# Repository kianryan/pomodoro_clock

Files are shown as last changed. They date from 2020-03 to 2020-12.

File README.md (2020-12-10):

## Introduction

Pomodoro Clock for AtTiny84 and MAX7219.

## Prerequisites

Arduino Cli

```
choco install arduino-cli
```

Install ATTinyCore Core

```
arduino-cli core install ATTinyCore:avr
```

## Building

* Arduino CLI
* USBAsp

Compiles, generates build asset in /build and uploads via ASP.

```
arduino-cli compile --fqbn ATTinyCore:avr:attinyx4; arduino-cli upload --fqbn ATTinyCore:avr:attinyx4 -P usbasp
```

## Board and Schematics

Eagle designs are available in /eagle

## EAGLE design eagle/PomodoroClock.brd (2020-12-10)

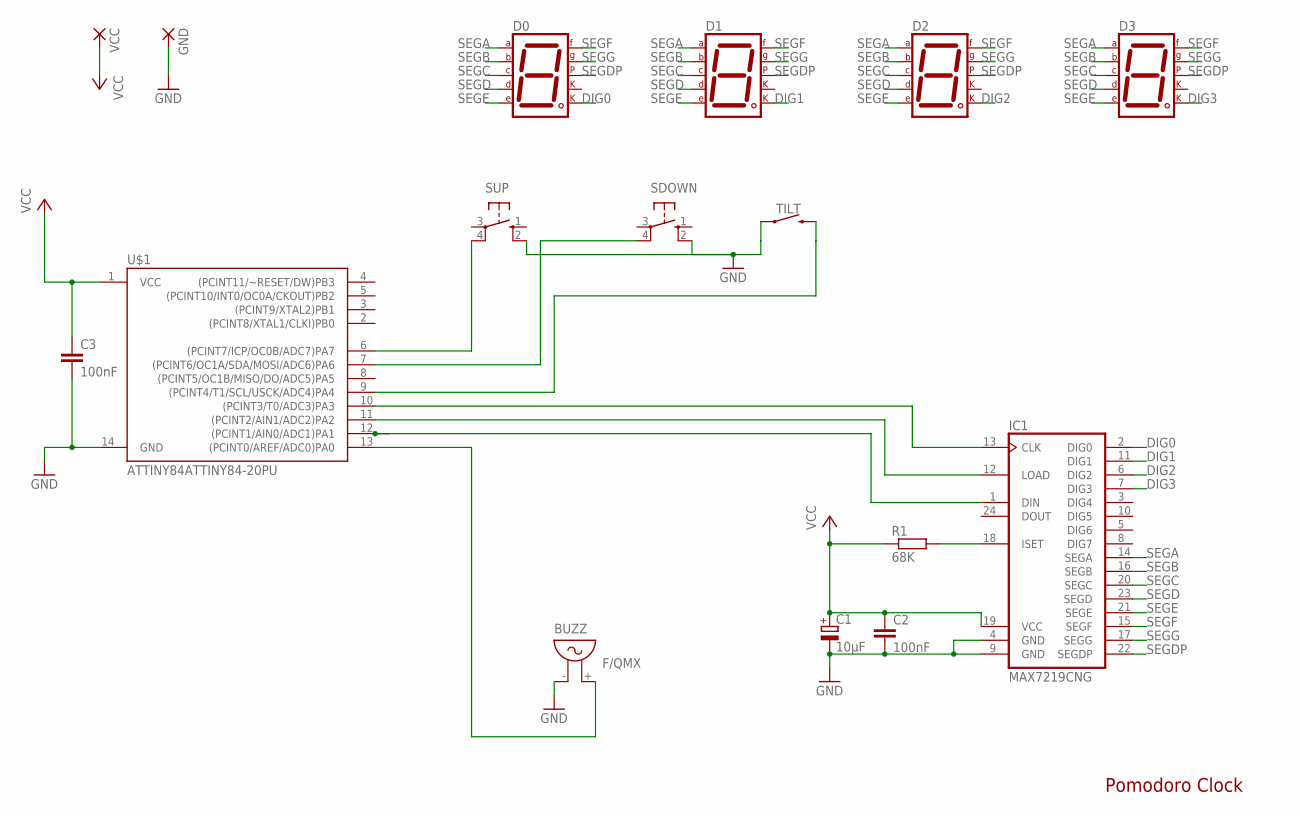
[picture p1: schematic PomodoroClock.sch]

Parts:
BUZZ: F/QMX
C1: 10μF; E2,5-6E
C2, C3: 100nF; C025-025X050
D0, D1, D2, D3: 7SEG-CK; 7SEG-13
GND: 3,81/1,4
IC1: MAX7219CNG; DIL24-3
R1: 68K; 0207/10
SDOWN: 10-XX; B3F-10XX
SUP: 10-XX; B3F-10XX
TILT: TILT
U$1: ATTINY84ATTINY84-20PU; DIP14
VCC: 3,81/1,4

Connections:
DIG0: D0.8 (CK2), IC1.2 (DIG0)
DIG1: D1.8 (CK2), IC1.11 (DIG1)
DIG2: D2.8 (CK2), IC1.6 (DIG2)
DIG3: D3.8 (CK2), IC1.7 (DIG3)
GND: BUZZ.- (1), C1.-, C2.2, C3.2, GND.1, IC1.4 (GND), IC1.9 (GND), SDOWN.2 (S1), SUP.2 (S1), TILT.1 (3), U$1.14 (GND)
unnamed: IC1.13 (CLK), U$1.10 ((PCINT3/T0/ADC3)PA3)
unnamed: IC1.12 (LOAD), U$1.11 ((PCINT2/AIN1/ADC2)PA2)
unnamed: IC1.1 (DIN), U$1.12 ((PCINT1/AIN0/ADC1)PA1)
unnamed: BUZZ.+ (2), U$1.13 ((PCINT0/AREF/ADC0)PA0)
unnamed: SUP.4 (P1), U$1.6 ((PCINT7/ICP/OC0B/ADC7)PA7)
unnamed: SDOWN.4 (P1), U$1.7 ((PCINT6/OC1A/SDA/MOSI/ADC6)PA6)
unnamed: IC1.18 (ISET), R1.2
SEGA: D0.7 (A), D1.7 (A), D2.7 (A), D3.7 (A), IC1.14 (SEGA)
SEGB: D0.6 (B), D1.6 (B), D2.6 (B), D3.6 (B), IC1.16 (SEGB)
SEGC: D0.4 (C), D1.4 (C), D2.4 (C), D3.4 (C), IC1.20 (SEGC)
SEGD: D0.2 (D), D1.2 (D), D2.2 (D), D3.2 (D), IC1.23 (SEGD)
SEGDP: D0.5 (DP), D1.5 (DP), D2.5 (DP), D3.5 (DP), IC1.22 (SEGDP)
SEGE: D0.1 (E), D1.1 (E), D2.1 (E), D3.1 (E), IC1.21 (SEGE)
SEGF: D0.9 (F), D1.9 (F), D2.9 (F), D3.9 (F), IC1.15 (SEGF)
SEGG: D0.10 (G), D1.10 (G), D2.10 (G), D3.10 (G), IC1.17 (SEGG)
TILT: TILT.2 (4), U$1.9 ((PCINT4/T1/SCL/USCK/ADC4)PA4)
VCC: C1.+, C2.1, C3.1, IC1.19 (VCC), R1.1, U$1.1 (VCC), VCC.1

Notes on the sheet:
Pomodoro Clock

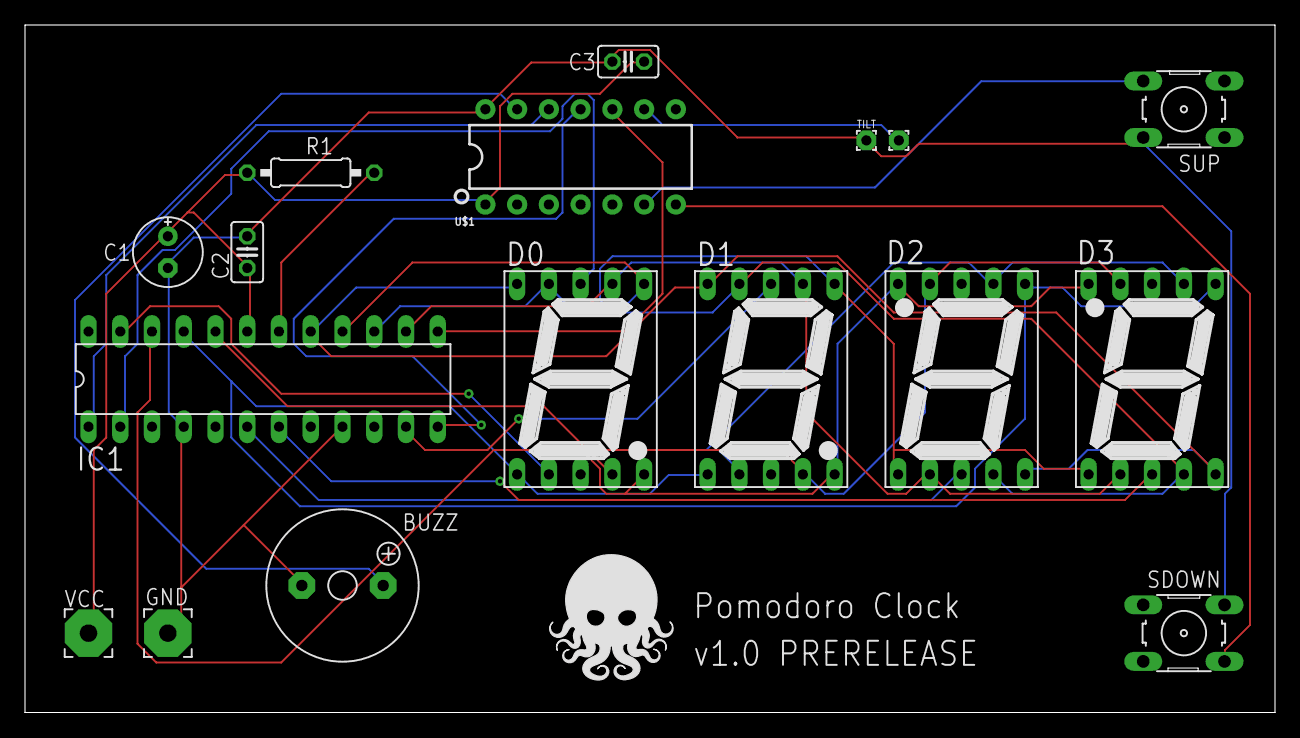
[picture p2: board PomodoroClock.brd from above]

Board: 2 copper layers, 100.0 x 55.0 mm, 16 parts (0 on the bottom side), 22 nets.

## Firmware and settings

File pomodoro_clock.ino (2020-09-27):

#include "LedControl.h"
#include "MilliClock.h"
#include "PomoTimer.h"
#include "TiltSwitch.h"
#include "EasingButton.h"
#include "ButtonManager.h"
#include "UiManager.h"
#include "Preflight.h"
#include <EEPROM.h>

MilliClock rtc;

int timers[] = {0, 0};

PomoTimer timer(&rtc);
TiltSwitch tiltSwitch(4);
ButtonManager buttonManager(&rtc, 6, 7, 5);
UiManager uiManager(&rtc, 1, 3, 2, 0);
Preflight preflight(&rtc, &timer);

bool direction;

bool alarmSilenced;


void setup() {

   // Serial for debugging
//    Serial.begin(9600);

   uiManager.startup();
   delay(1000);

   /* Initialize EEPROM, or timers from EEPROM */
   byte init = EEPROM.read(0);
//    if (init == 255) {
       timers[0] = 1200;
       timers[1] = 300;
    //    EEPROM.put(1, timers[0]);
    //    EEPROM.put(sizeof(int) + 1, timers[1]);
    //    EEPROM.put(0, 0);
//    } else {
//        EEPROM.get(1, timers[0]);
//        EEPROM.get(sizeof(int) + 1, timers[1]);
//    }

   direction = tiltSwitch.getState(); // Get an inital direction.
   preflight.start(timers[direction]);
}

void loop() {

    tiltSwitch.update();
    buttonManager.update();

    // On a change in tilt state,
    bool newDirection = tiltSwitch.getState();
    if (direction != newDirection) {
        direction = newDirection;

        preflight.start(timers[direction]);
    }

    if (preflight.isRunning()) {

        /* Take button input, if button press, increase duration
           of preflight, and increase time displayed on clock. */

        // check the button state.
        bool pause = false;
        switch (buttonManager.getState()) {
           case CHANGE_TIMER:
                int change = buttonManager.getChange(direction);

                timers[direction] = timer.changeTime(change);
                pause = true;
                break;
        }

       TimeSpan interval = preflight.time(pause); // get preflight time.
       if (interval.milliseconds() == 0) {        // update EEPROM with last set time.
           EEPROM.put((direction * sizeof(int)) + 1, timers[direction]);
           uiManager.resetAlarm();
       }

        if (preflight.isDisplayOn()) {
            uiManager.display(timer.time().totalseconds(), direction);
        } else {
            uiManager.clearDisplay();
        }
    } else {

        // check the button state.
        int buttonState = buttonManager.getState();
        switch (buttonState) {
            case NO_BUTTON:
                // Nothing to do here.
                break;
            case TOGGLE_TIMER:
                timer.startStop();
                break;
            case CHANGE_TIMER:
                timer.changeTime(buttonManager.getChange(direction));
                break;
        }

        // Get the time from the timer and display.
        TimeSpan interval = timer.time();
        unsigned long millis = interval.milliseconds();

        // If the timer is not currently running,
        // and there's time on the clock, start the timer.
        if (millis > 0 && ! timer.isRunning()) {
            uiManager.resetAlarm();
            timer.start();
        }
        // If there's no time on the clock, alarm.
        // If the button is depressed, silence.
        else if (millis == 0) {
            if (buttonState != NO_BUTTON) {
                uiManager.silenceAlarm();
            }
            uiManager.alarm();
        }

        uiManager.display(interval.totalseconds(), direction);
   }
}

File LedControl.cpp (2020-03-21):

/*
 *    LedControl.cpp - A library for controling Leds with a MAX7219/MAX7221
 *    Copyright (c) 2007 Eberhard Fahle
 *
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
 *    This permission notice shall be included in all copies or
 *    substantial portions of the Software.
 *
 *    THE SOFTWARE IS PROVIDED "AS IS", WITHOUT WARRANTY OF ANY KIND,
 *    EXPRESS OR IMPLIED, INCLUDING BUT NOT LIMITED TO THE WARRANTIES
 *    OF MERCHANTABILITY, FITNESS FOR A PARTICULAR PURPOSE AND
 *    NONINFRINGEMENT. IN NO EVENT SHALL THE AUTHORS OR COPYRIGHT
 *    HOLDERS BE LIABLE FOR ANY CLAIM, DAMAGES OR OTHER LIABILITY,
 *    WHETHER IN AN ACTION OF CONTRACT, TORT OR OTHERWISE, ARISING
 *    FROM, OUT OF OR IN CONNECTION WITH THE SOFTWARE OR THE USE OR
 *    OTHER DEALINGS IN THE SOFTWARE.
 */


#include "LedControl.h"

//the opcodes for the MAX7221 and MAX7219
#define OP_NOOP   0
#define OP_DIGIT0 1
#define OP_DIGIT1 2
#define OP_DIGIT2 3
#define OP_DIGIT3 4
#define OP_DIGIT4 5
#define OP_DIGIT5 6
#define OP_DIGIT6 7
#define OP_DIGIT7 8
#define OP_DECODEMODE  9
#define OP_INTENSITY   10
#define OP_SCANLIMIT   11
#define OP_SHUTDOWN    12
#define OP_DISPLAYTEST 15

LedControl::LedControl(int dataPin, int clkPin, int csPin, int numDevices) {
    SPI_MOSI=dataPin;
    SPI_CLK=clkPin;
    SPI_CS=csPin;
    if(numDevices<=0 || numDevices>8 )
        numDevices=8;
    maxDevices=numDevices;
    pinMode(SPI_MOSI,OUTPUT);
    pinMode(SPI_CLK,OUTPUT);
    pinMode(SPI_CS,OUTPUT);
    digitalWrite(SPI_CS,HIGH);
    SPI_MOSI=dataPin;
    for(int i=0;i<64;i++)
        status[i]=0x00;
    for(int i=0;i<maxDevices;i++) {
        spiTransfer(i,OP_DISPLAYTEST,0);
        //scanlimit is set to max on startup
        setScanLimit(i,7);
        //decode is done in source
        spiTransfer(i,OP_DECODEMODE,0);
        clearDisplay(i);
        //we go into shutdown-mode on startup
        shutdown(i,true);
    }
}

int LedControl::getDeviceCount() {
    return maxDevices;
}

void LedControl::shutdown(int addr, bool b) {
    if(addr<0 || addr>=maxDevices)
        return;
    if(b)
        spiTransfer(addr, OP_SHUTDOWN,0);
    else
        spiTransfer(addr, OP_SHUTDOWN,1);
}

void LedControl::setScanLimit(int addr, int limit) {
    if(addr<0 || addr>=maxDevices)
        return;
    if(limit>=0 && limit<8)
        spiTransfer(addr, OP_SCANLIMIT,limit);
}

void LedControl::setIntensity(int addr, int intensity) {
    if(addr<0 || addr>=maxDevices)
        return;
    if(intensity>=0 && intensity<16)
        spiTransfer(addr, OP_INTENSITY,intensity);
}

void LedControl::clearDisplay(int addr) {
    int offset;

    if(addr<0 || addr>=maxDevices)
        return;
    offset=addr*8;
    for(int i=0;i<8;i++) {
        status[offset+i]=0;
        spiTransfer(addr, i+1,status[offset+i]);
    }
}

void LedControl::setLed(int addr, int row, int column, boolean state) {
    int offset;
    byte val=0x00;

    if(addr<0 || addr>=maxDevices)
        return;
    if(row<0 || row>7 || column<0 || column>7)
        return;
    offset=addr*8;
    val=B10000000 >> column;
    if(state)
        status[offset+row]=status[offset+row]|val;
    else {
        val=~val;
        status[offset+row]=status[offset+row]&val;
    }
    spiTransfer(addr, row+1,status[offset+row]);
}

void LedControl::setRow(int addr, int row, byte value) {
    int offset;
    if(addr<0 || addr>=maxDevices)
        return;
    if(row<0 || row>7)
        return;
    offset=addr*8;
    status[offset+row]=value;
    spiTransfer(addr, row+1,status[offset+row]);
}

void LedControl::setColumn(int addr, int col, byte value) {
    byte val;

    if(addr<0 || addr>=maxDevices)
        return;
    if(col<0 || col>7)
        return;
    for(int row=0;row<8;row++) {
        val=value >> (7-row);
        val=val & 0x01;
        setLed(addr,row,col,val);
    }
}

void LedControl::setDigit(int addr, int digit, byte value, boolean dp) {
    int offset;
    byte v;

    if(addr<0 || addr>=maxDevices)
        return;
    if(digit<0 || digit>7 || value>15)
        return;
    offset=addr*8;
    v=pgm_read_byte_near(charTable + value);
    if(dp)
        v|=B10000000;
    status[offset+digit]=v;
    spiTransfer(addr, digit+1,v);
}

void LedControl::setInverseDigit(int addr, int digit, byte value, boolean dp) {
    int offset;
    byte v;

    if(addr<0 || addr>=maxDevices)
        return;
    if(digit<0 || digit>7 || value>15)
        return;
    offset=addr*8;
    v=pgm_read_byte_near(inverseDigitTable + value);
    if(dp)
        v|=B10000000;
    status[offset+digit]=v;
    spiTransfer(addr, digit+1,v);
}

void LedControl::setChar(int addr, int digit, char value, boolean dp) {
    int offset;
    byte index,v;

    if(addr<0 || addr>=maxDevices)
        return;
    if(digit<0 || digit>7)
        return;
    offset=addr*8;
    index=(byte)value;
    if(index >127) {
        //no defined beyond index 127, so we use the space char
        index=32;
    }
    v=pgm_read_byte_near(charTable + index);
    if(dp)
        v|=B10000000;
    status[offset+digit]=v;
    spiTransfer(addr, digit+1,v);
}

void LedControl::spiTransfer(int addr, volatile byte opcode, volatile byte data) {
    //Create an array with the data to shift out
    int offset=addr*2;
    int maxbytes=maxDevices*2;

    for(int i=0;i<maxbytes;i++)
        spidata[i]=(byte)0;
    //put our device data into the array
    spidata[offset+1]=opcode;
    spidata[offset]=data;
    //enable the line
    digitalWrite(SPI_CS,LOW);
    //Now shift out the data
    for(int i=maxbytes;i>0;i--)
        shiftOut(SPI_MOSI,SPI_CLK,MSBFIRST,spidata[i-1]);
    //latch the data onto the display
    digitalWrite(SPI_CS,HIGH);
}

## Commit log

2020-03-22 Detect when tilt changes and reset timer.
    [TiltSwitch.cpp, pomodoro_clock.ino]
2020-03-22 Add easing button, accl change state.
2020-03-22 Add a decreasing button.
2020-03-28 Change PomoTimer to track elapsed time over DateTime
2020-03-29 Build a button manager to handle button states
2020-04-10 Switch RTC clock to use internal Mills
2020-04-13 Replace ADAFruit RTCClock with MilliClock
    RTCClock can only count in seconds - use MilliClock which can count in milliseconds.
2020-04-13 Pause timer on pre-flight
2020-04-20 Boundary conditions for setting timers
2020-04-20 Store timer values in EEPROM. Read/write before flight
2020-04-20 Inverse buttons based on direction
2020-04-20 Add "bump" in timer when at zero, remove serial
2020-09-27 Add ignore for arduino cli build
2020-09-27 UiManager now uses straight digit wiring...
    I meant to do that.
2020-12-10 Add eagle designs
    [PomodoroClock.brd, PomodoroClock.sch]

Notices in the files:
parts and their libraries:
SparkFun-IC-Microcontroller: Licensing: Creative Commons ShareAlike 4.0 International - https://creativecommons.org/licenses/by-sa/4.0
